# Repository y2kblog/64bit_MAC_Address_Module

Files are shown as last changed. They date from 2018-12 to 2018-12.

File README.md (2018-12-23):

# 64bit MACアドレスモジュール

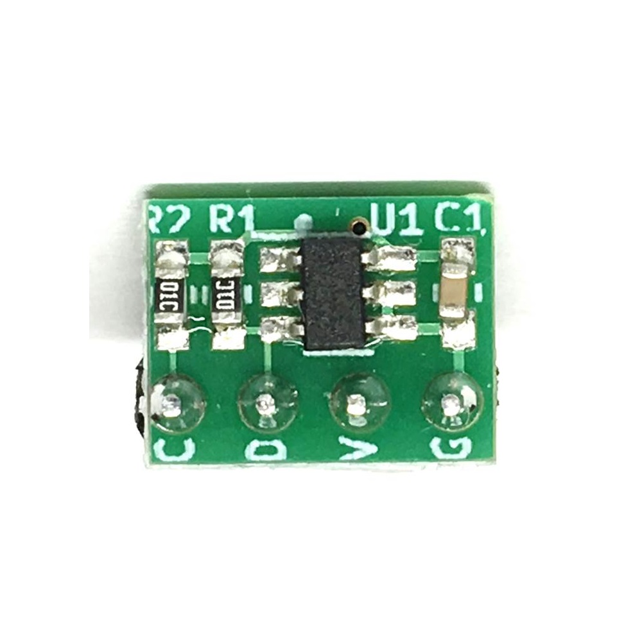
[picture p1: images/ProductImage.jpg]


## 概要

64bit MACアドレスモジュールはMicrochip社のI2C接続のMACアドレス書き込み済みEEPROM 24AA025E64を2.54mmピッチに変換したモジュールです。  
IPv6、ZigBee、FireWire等のネットワーク接続デバイスに一意の64bit MACアドレス(EUI-64)を割り当てることができます。  
ピンヘッダ含め部品は全て実装済みのため**はんだ付け作業は一切不要**です。また、**Arudinoシールド等に直接挿せるピン配置**となっているため、ジャンパワイヤ等を使わず手軽に接続できます。  
**MACアドレスを記載したカードを同梱。**

※48bit MACアドレス版は[こちら](https://github.com/y2kblog/48bit_MAC_Address_Module)

### 仕様
- 搭載IC：Microchip 24AA025E64T-I/OT
- メモリ容量：2Kbits (内ユーザ書込み可能領域：1Kbits)
- インターフェイス：I2C (最大400kHz)
- I2Cアドレス：0x50
- 電源電圧：1.7V～5.5V
- 最大消費電流
    - 読込み時：1mA
    - 書込み時：3mA
    - 待機時：1μA
- 基板サイズ：横10.0 mm × 縦7.5 mm

### 内容物
- 64bit MACアドレスモジュール本体
- MACアドレス記載カード

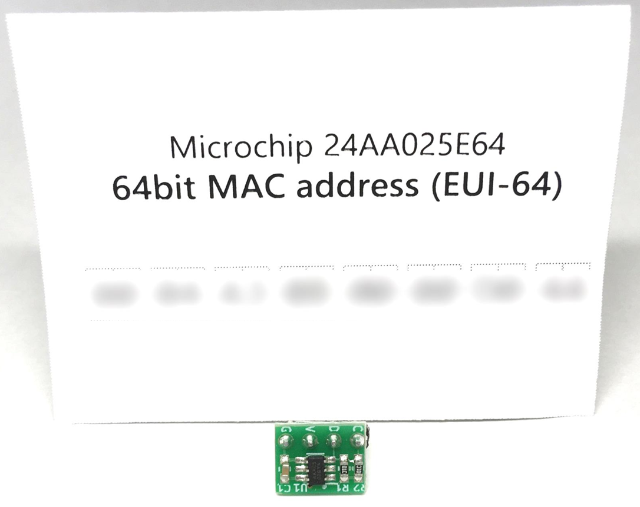
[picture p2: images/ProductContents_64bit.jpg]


## 販売  
[スイッチサイエンス委託販売ページ](https://www.switch-science.com/catalog/5319/)  
※大量注文や在庫に関する問い合わせは[こちら](mailto:info.y2kb@gmail.com)までご連絡ください。  

### 回路図

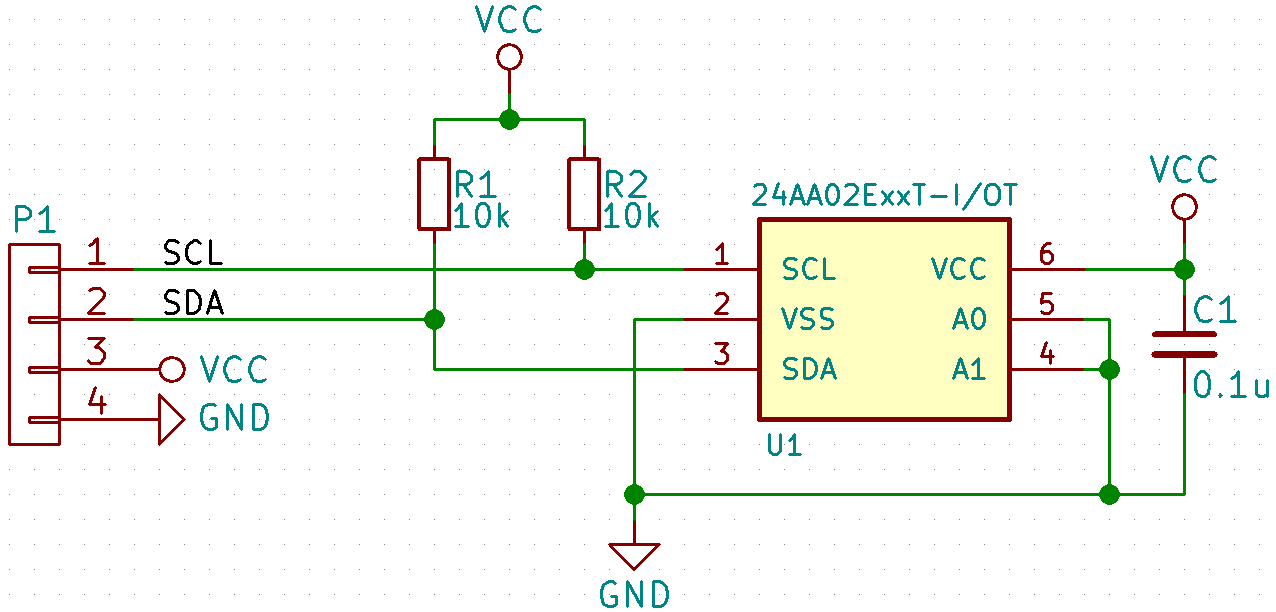
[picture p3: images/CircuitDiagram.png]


### Arduinoによるプログラム例

#### 接続方法  

Arudino UNOの場合、下の写真のように挿すだけでOKです。

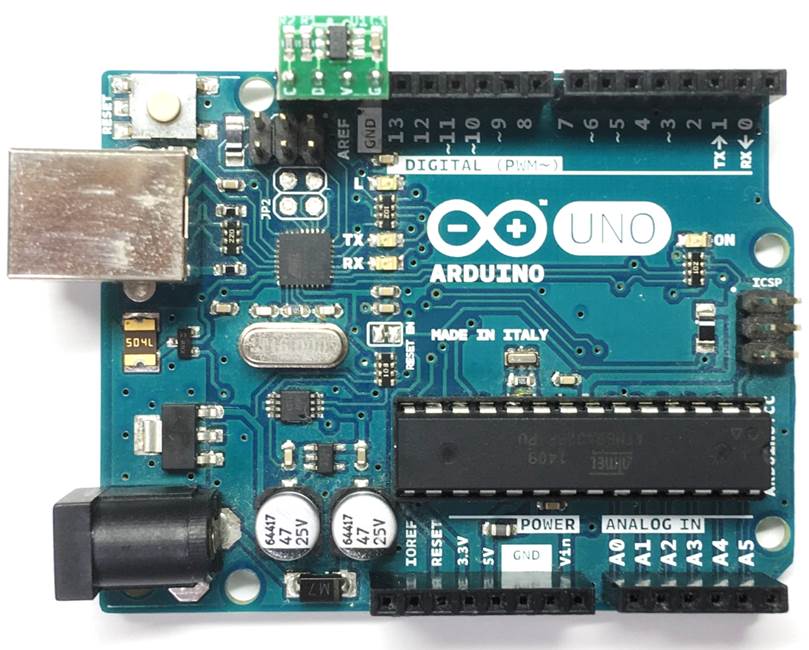
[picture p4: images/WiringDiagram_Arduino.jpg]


#### ミニマムコード

    #include <stdio.h>
    #include <stdint.h>
    #include <Wire.h>

    #define MAC_24AA02Exx_DEV_ADDR        0x50
    #define MAC_24AA02Exx_REG_ADDR_MAC    0xF8

    void setup() {
      Serial.begin(115200);
      while (!Serial);

      // execute ADC one time in order to power the Arduino AREF pin
      analogRead(A0);
      delay(1);  // Wait until the IC starts up

      // I2C init and read MAC address
      Wire.begin();
      Wire.setClock(100000);
      Wire.beginTransmission(MAC_24AA02Exx_DEV_ADDR);
      Wire.write(MAC_24AA02Exx_REG_ADDR_MAC);
      Wire.endTransmission(false);
      Wire.requestFrom(MAC_24AA02Exx_DEV_ADDR, 8);
      uint8_t MAC_addr_buf[8] = {'\0'};
      for(int i = 0; i < 8; i++)
        MAC_addr_buf[i] = Wire.read();

      // Determine whether the MAC address is EUI-48 or EUI-64
      int MAC_bytes;
      uint8_t MAC_addr[8] = {'\0'};
      if( (MAC_addr_buf[0] == 0xFF) && (MAC_addr_buf[1] == 0xFF) ) {
        MAC_bytes = 6;  // EUI-48 (24AA02xE48)
        memcpy(MAC_addr, MAC_addr_buf + 2, MAC_bytes);
      } else {
        MAC_bytes = 8;  // EUI-64 (24AA02xE64)
        memcpy(MAC_addr, MAC_addr_buf, MAC_bytes);
      }

      // print MAC address
      Serial.print(8 * MAC_bytes);
      Serial.print("bit MAC address : ");
      for(int i = 0; i < MAC_bytes; i++) {
        char strBuf[3];
        sprintf(strBuf, "%02X", MAC_addr[i]);
        Serial.print(strBuf);
        if(i < (MAC_bytes - 1))
          Serial.print("-");
      }
      Serial.println();
    }

    void loop() {
    }

### Nucleoによるプログラム例

#### 接続方法  

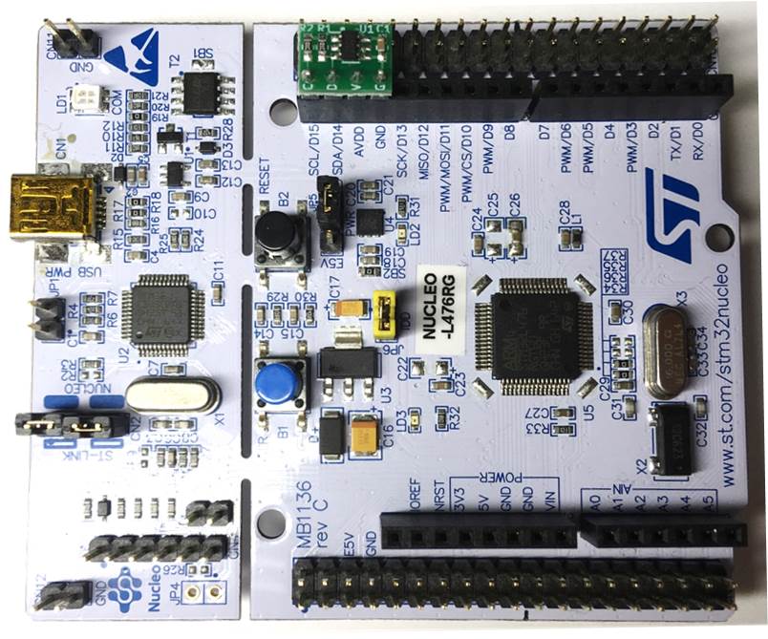
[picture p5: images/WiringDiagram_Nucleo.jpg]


#### ソースコード

NUCLEO-L476RGのソースコードは[こちら](https://github.com/y2kblog/64bit_MAC_Address_Module/blob/master/SampleCode/NUCLEO-L476RG/24AA025Exx_testing) (IDE：SW4STM32)

## License
MIT License, see LICENSE.txt.

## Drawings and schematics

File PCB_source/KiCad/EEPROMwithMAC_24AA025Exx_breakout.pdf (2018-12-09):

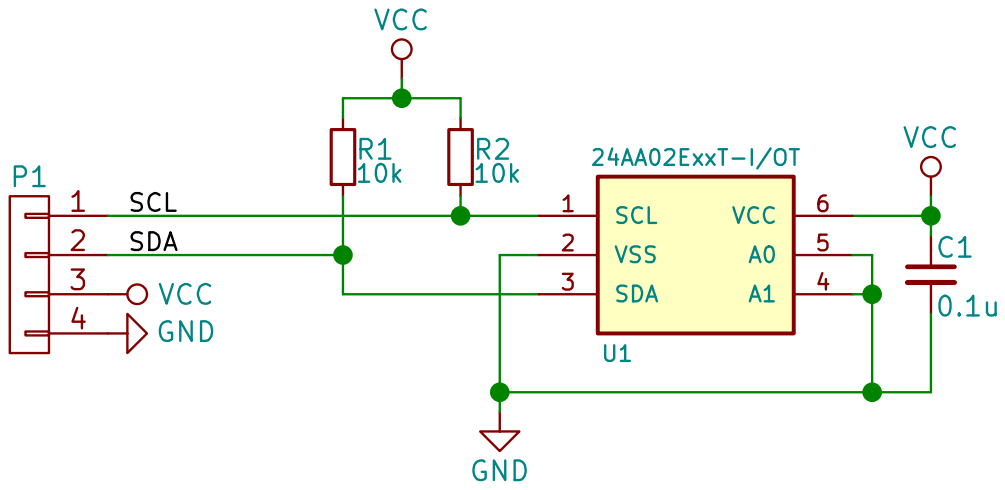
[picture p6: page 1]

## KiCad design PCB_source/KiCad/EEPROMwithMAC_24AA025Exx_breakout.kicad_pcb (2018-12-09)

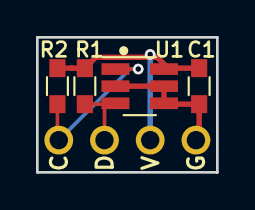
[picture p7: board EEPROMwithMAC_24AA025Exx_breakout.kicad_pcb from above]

Board: 2 copper layers, 10.0 x 7.5 mm, 5 parts (1 on the bottom side), 4 nets.

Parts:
C1: 0.1u; USER_0603_HandSoldering
P1: CONN_01X04; USER_SIL-4_PinHeader2
R1, R2: 10k; USER_0603_HandSoldering
U1: 24AA02ExxT-I/OT; SOT-23-6_Handsoldering

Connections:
/SCL: P1.1, R2.2, U1.1
/SDA: P1.2, R1.2, U1.3
GND: C1.2, P1.4, U1.2, U1.4, U1.5
VCC: C1.1, P1.3, R1.1, R2.1, U1.6

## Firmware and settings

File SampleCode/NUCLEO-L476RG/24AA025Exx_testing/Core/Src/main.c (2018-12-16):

/**
  ******************************************************************************
  * @file           : main.c
  * @brief          : Main program body
  ******************************************************************************
  ** This notice applies to any and all portions of this file
  * that are not between comment pairs USER CODE BEGIN and
  * USER CODE END. Other portions of this file, whether 
  * inserted by the user or by software development tools
  * are owned by their respective copyright owners.
  *
  * COPYRIGHT(c) 2018 STMicroelectronics
  *
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
  ******************************************************************************
  */
/* Includes ------------------------------------------------------------------*/
#include "main.h"
#include "stm32l4xx_hal.h"
#include "i2c.h"
#include "usart.h"
#include "gpio.h"

/* USER CODE BEGIN Includes */
#include "MAC_24AA02Exx_HAL.h"

/* USER CODE END Includes */


/* USER CODE BEGIN PV */

/* USER CODE END PV */

void SystemClock_Config(void);

/* USER CODE BEGIN PFP */

/* USER CODE END PFP */

/**
  * @brief  The application entry point.
  *
  * @retval None
  */
int main(void)
{
  /* MCU Configuration----------------------------------------------------------*/

  /* Reset of all peripherals, Initializes the Flash interface and the Systick. */
  HAL_Init();

  /* Configure the system clock */
  SystemClock_Config();

  /* Initialize all configured peripherals */
  MX_GPIO_Init();
  MX_USART2_UART_Init();
  MX_I2C1_Init();
  /* USER CODE BEGIN 2 */
  HAL_Delay(10);

  uint8_t MAC_addr[8] = {'\0'};
  bool isEUI48;
  if(get_MAC_address(&hi2c1, &isEUI48, MAC_addr)) {
	  if(isEUI48) {
		  // EUI-48
		  printf("EUI-48,");
		  for(int i = 0; i < (6-1); i++)
			  printf("%02X-", MAC_addr[i]);
		  printf("%02X\r\n", MAC_addr[6-1]);
	  } else {
		  // EUI-64
		  printf("EUI-64,");
		  for(int i = 0; i < (8-1); i++)
			  printf("%02X-", MAC_addr[i]);
		  printf("%02X\r\n", MAC_addr[8-1]);
	  }
  }
  else {
	  printf("get_MAC_address false\r\n");
  }


  /* USER CODE END 2 */

  /* Infinite loop */
  /* USER CODE BEGIN WHILE */
  while (1)
  {

  /* USER CODE END WHILE */

  /* USER CODE BEGIN 3 */

  }
  /* USER CODE END 3 */

}

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
/* USER CODE BEGIN 4 */
int _write(int file, char *ptr, int len)
{
    HAL_UART_Transmit(&huart2, (uint8_t*) ptr, (uint16_t)len, 1000);
    return len;
}

/* USER CODE END 4 */
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


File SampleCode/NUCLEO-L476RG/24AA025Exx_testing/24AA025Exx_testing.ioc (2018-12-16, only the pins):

Mcu.UserName=STM32L476RGTx
PA2.GPIO_Label=USART_TX
PA2.Signal=USART2_TX
PA3.GPIO_Label=USART_RX
PA3.Signal=USART2_RX
PA5.GPIO_Label=LD2 [green Led]
PA5.Signal=GPIO_Output
PB8.Signal=I2C1_SCL
PB9.Signal=I2C1_SDA
PC13.GPIO_Label=B1 [Blue PushButton]
PC13.Signal=GPXTI13

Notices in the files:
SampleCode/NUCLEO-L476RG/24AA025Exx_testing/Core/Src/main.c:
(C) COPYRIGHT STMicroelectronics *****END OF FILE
